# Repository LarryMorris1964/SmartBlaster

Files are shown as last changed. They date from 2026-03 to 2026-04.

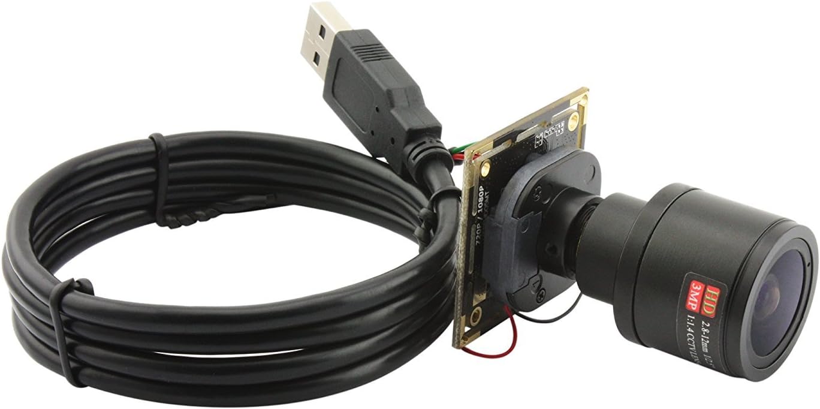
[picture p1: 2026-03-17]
hardware/Reference images/Camera/613zbUWkeIL._AC_SL1500_.jpg

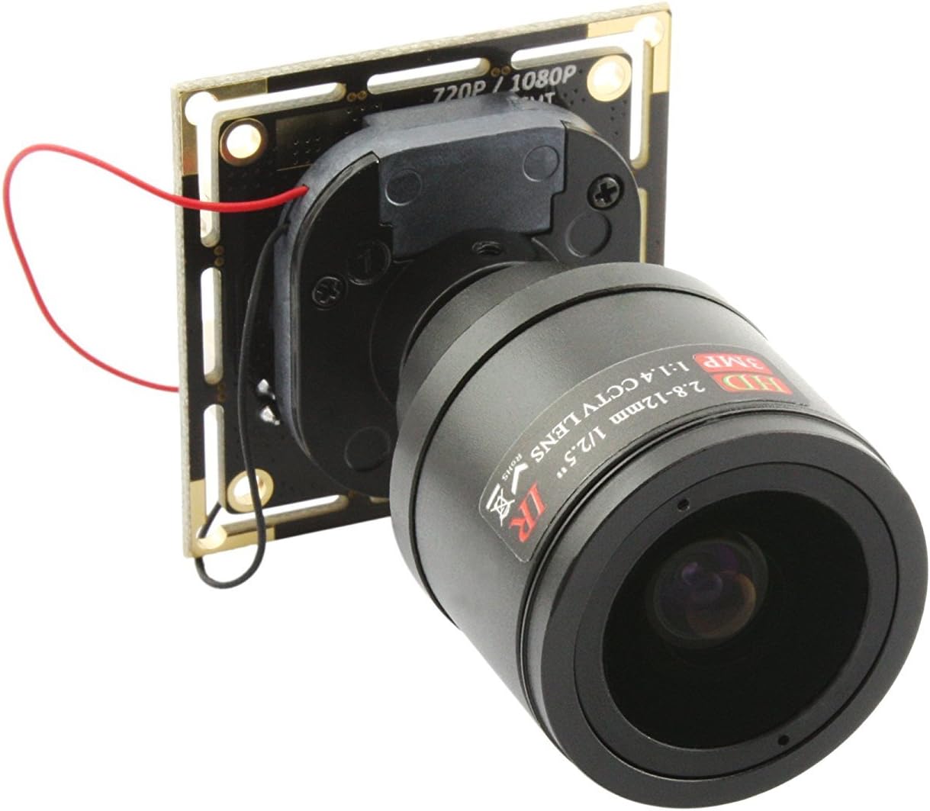
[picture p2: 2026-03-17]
hardware/Reference images/Camera/71GznruDwVL._AC_SL1500_.jpg

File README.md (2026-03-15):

# SmartBlaster — Open Smart HVAC Controller

SmartBlaster is an open-source, wall-mounted HVAC controller featuring:

- A landscape camera for visual feedback
- IR control for mini-splits and AC units
- A sleek, thermostat-like enclosure
- Modular hardware and software design
- Hobbyist-friendly assembly and open collaboration

This repository contains:

- **Hardware** (enclosure CAD, electronics, mechanical specs)
- **Software** (Python-based control logic, drivers, tools)
- **Documentation** (assembly, wiring, printing, troubleshooting)

Contributions are welcome!

A Raspberry Pi-based smart device. This repo contains both hardware design files and the Python software stack.

## Repository Layout

```
SmartBlaster/
├── hardware/
│   ├── enclosure/revA/     3D-printable enclosure parts (.obj)
│   ├── electronics/        Schematics, PCB files, BOM
│   └── mechanical_specs/   Reference dimensions and tolerances
├── software/               Python source, tests, dependencies
├── docs/                   Assembly guide, wiring diagrams, troubleshooting
└── LICENSE
```

## Quick Start

### Hardware
See [docs/assembly_guide.md](docs/assembly_guide.md) for full build instructions and [docs/wiring.md](docs/wiring.md) for wiring diagrams.

3D print files are in `hardware/enclosure/revA/`. All parts are designed for standard FDM printing (PLA or PETG recommended).

### Software
```bash
cd software
python -m venv .venv
source .venv/bin/activate      # Windows: .venv\Scripts\activate
pip install -r requirements.txt
python src/main.py
```

## Hardware Revision History

| Rev | Status | Notes |
|-----|---|---|
| A | Current | Initial release |
| B | Planned | TBD |

## License
See [LICENSE](LICENSE).

## Project Manifest

SmartBlaster is defined by the following core constraints:

- Camera PCB: 32 × 32 mm, 14 mm deep
- Lens: 27 mm diameter, 45 mm long
- Required rear clearance: 14 mm
- IR module: 23.5 × 21.5 mm, 5 mm LED height
- Enclosure internal depth: 61 mm
- Landscape orientation
- IR LED offset: +25 mm X

These constraints drive both the enclosure geometry and the software architecture.

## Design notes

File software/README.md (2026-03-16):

# SmartBlaster Software

Python application that runs on the Raspberry Pi.

## Structure

```
software/
├── src/
│   └── main.py     Entry point
├── tests/          pytest test suite
└── requirements.txt
```

## Setup

```bash
python -m venv .venv
source .venv/bin/activate      # Windows: .venv\Scripts\activate
pip install -r requirements.txt
```

## Run

```bash
python src/main.py
```

## Test

```bash
pytest
```

## Project Diary

An AI-assisted build diary lives in `docs/AI_DIARY.md`.

## Project Backlog

A running project backlog lives in `docs/PROJECT_BACKLOG.md`.

## New Scaffolded Modules

- `src/smartblaster/config.py` — runtime settings from environment variables
- `src/smartblaster/hardware/` — camera + IR adapters
- `src/smartblaster/control/state_machine.py` — HVAC control state skeleton
- `src/smartblaster/services/runtime.py` — runtime wiring and loop

Run with:

```bash
python -m smartblaster
```

## CLI (ESP32 IR Bridge)

Send commands to the ESP32 bridge over serial:

```bash
smartblaster-cli --serial-port COM3 set --mode cool --temp 24 --fan medium --swing vertical
smartblaster-cli --serial-port COM3 off
```

Request thermostat status via camera parse pipeline:

```bash
smartblaster-cli status --model-id midea_kjr_12b_dp_t \
	--history-file data/thermostat_status_history.log
```

Enable diagnostic mode to also save each captured image for verification:

```bash
smartblaster-cli status --diagnostic-save-images --diagnostic-image-dir data/status_images
```

The status request flow is:
- capture camera frame
- parse display indicators (mode/fan/timer/follow-me/power/setpoint)
- append a text-readable JSON-lines history record
- optionally save source image in diagnostic mode

## Offline Vision Validation (No Live Thermostat Required)

You can evaluate parser quality against labeled JPEG samples without a full HVAC system:

```bash
smartblaster-cli vision-eval \
	--model-id midea_kjr_12b_dp_t \
	--images-dir data/samples/midea \
	--labels-file data/samples/midea/labels.jsonl \
	--output-report data/vision_eval_report.json
```

Use `data/samples/midea/labels.sample.jsonl` as a template for labels.

Validate labels before running evaluation:

```bash
smartblaster-cli vision-validate-labels \
	--labels-file data/samples/midea/labels.sample.jsonl \
	--images-dir data/samples/midea
```

If validation fails, the command prints each issue and exits non-zero.

Full label schema reference:
- `data/samples/midea/labels.schema.json`

## Runtime Event Dispatch

The runtime loop now maps high-level events to typed Midea commands:

- `cool_requested` -> COOL command
- `heat_requested` -> HEAT command
- `dry_requested` -> DRY command
- `fan_requested` -> FAN_ONLY command
- `stop_requested` -> OFF command

When state changes, runtime emits a `midea_ir.command` frame via `IrService.send_midea_command()`.

## Daily Automation (Initial Solar Approximation)

Configure fixed daily on/off events via environment variables:

- `SMARTBLASTER_DAILY_ON_TIME` (HH:MM, local time)
- `SMARTBLASTER_DAILY_OFF_TIME` (HH:MM, local time)
- `SMARTBLASTER_TARGET_TEMPERATURE_C`
- `SMARTBLASTER_SOLAR_WEEKLY_SCHEDULE_JSON` (optional per-day override JSON)

Default schedule is 10:00 ON and 15:00 OFF.
Default target setpoint is 26C (about 78.8F).

Example weekly schedule JSON:

```json
{
	"mon": {"on_time": "09:45", "off_time": "15:30"},
	"tue": {"on_time": "10:00", "off_time": "15:00"}
}
```

Current behavior:
- At `DAILY_ON_TIME`, SmartBlaster emits `cool_requested` and sends a COOL command at the target temperature.
- At `DAILY_OFF_TIME`, SmartBlaster emits `stop_requested` and sends OFF.
- Temperature control is sent as an explicit target setpoint in the IR payload (for example 24C), not as temp-up/temp-down button increments.
- Midea IR payload setpoints are encoded in Celsius (`temperature_c`), even when thermostat UI settings may be Fahrenheit-facing.
- Runtime treats thermostat timer state as informational; direct runtime ON/OFF commands are intended to supersede manual timer settings.

Future behavior:
- External stimuli (e.g., inverter/solar surplus signals) can inject events through `EventSource` implementations without replacing runtime/state-machine logic.

## Camera Optional Operation

SmartBlaster supports IR-only operation (no camera attached):

- Set `SMARTBLASTER_CAMERA_ENABLED=false`
- Runtime uses a no-op camera service and still executes all IR scheduling/dispatch

This enables a Sensibo-style launch mode where the device blasts IR commands without visual verification.

## Thermostat Profile Selection

Set `SMARTBLASTER_THERMOSTAT_PROFILE_ID` to select a supported profile from the thermostat library.

Current launch profile:
- `midea_kjr_12b_dp_t`

Profile metadata lives in `src/smartblaster/thermostats/library.py`.

Command execution policy is now profile-driven (criticality, retry count, retry wait), keyed by thermostat profile.
This keeps command behavior extensible across brands/models while reusing the same runtime flow.
At setup time, profile selection determines:
- IR protocol implementation
- camera support availability
- command policy defaults used by runtime (for current logging and future verification/retry orchestration)

## Captive Portal Provisioning Scaffold

Provisioning core logic is implemented in `src/smartblaster/provisioning/service.py`.
It validates setup payloads (Wi-Fi credentials, thermostat profile, camera mode) and persists setup state.

A future local web server/captive portal can call this module directly.

A local setup server scaffold is now available:

```bash
smartblaster-setup-server --host 0.0.0.0 --port 8080
```

Endpoints:
- `GET /` setup page (basic HTML)
- `GET /api/thermostats` profile options from library
- `POST /api/setup` validate and persist onboarding settings
- `GET /api/camera/status` live camera alignment metrics for the selected thermostat profile
- `GET /api/camera/preview.jpg` live preview JPEG with parser overlay banner
- `POST /api/camera/reference-capture` save install-time reference images with JSON metadata

The captive portal setup page now includes a `Camera Setup` section intended for headless installs:
- live preview with overlay
- parser readability/focus/glare feedback
- install-time reference image capture

Reference images are stored under `data/reference_images/<phase>/...` so the same storage layout can be reused later for runtime/support lifecycle snapshots.

Retention behavior:
- phase-specific FIFO retention (oldest captures pruned first, newest retained)
- higher default retention for high-value phases like `runtime_parse_failure`
- lower default retention for bulk phases like `training_periodic`

Offload readiness:
- each capture metadata file tracks offload state (`pending` / `offloaded`), attempt counts, and optional remote IDs
- this is intended to support future periodic upload/offload to a central server without changing on-device capture format

Offload skeleton (future work item):
- runtime includes a disabled-by-default offload worker scaffold that drains pending captures FIFO in batches
- current transport is a no-op placeholder; real server transport/auth/retry policy is still future work

Current lifecycle hook:
- runtime parse failures can automatically save the failed source image, overlay, and error context into the reference-image store

Status request behavior now supports two camera/parse paths:
- strict (`request_status`): used by command-verification logic; camera/parse failures are fatal to that transaction
- best-effort (`request_status_best_effort`): used by opportunistic workflows (for example periodic snapshots); camera/parse failures are non-fatal and returned as typed outcomes

Provisioning now also persists future-facing capture options:
- `reference_capture_on_parse_failure`
- `training_mode_enabled`
- `training_capture_interval_minutes`
- `validate_capabilities_enabled`

The training-mode and capability-validation workflows are not fully automated yet, but their settings now flow through setup state into runtime configuration so later hooks can reuse the same reference-image storage path.

## Device Bootstrap Mode

## Raspberry Pi OS Lite Deployment

Pi OS Lite (64-bit) is sufficient for SmartBlaster.

Deployment assets:
- First-boot setup script: `deploy/install/first_boot_setup.sh`
- Vision package install script (OpenCV, Tesseract, TFLite best-effort): `deploy/install/install_vision_stack.sh`
- Service installer: `deploy/install/install_service.sh`
- systemd unit: `deploy/systemd/smartblaster.service`
- Full image prep checklist: `docs/PI_IMAGE_PREP_CHECKLIST.md`

Typical bring-up flow on Pi:

```bash
cd ~/SmartBlaster/software
sudo ./deploy/install/first_boot_setup.sh
systemctl status smartblaster.service
```

Use one command to choose setup vs runtime automatically:

```bash
smartblaster-device --mode auto --state-file data/device_setup.json
```

Startup behavior:
- If setup state file is missing: run captive setup server mode.
- If setup state file exists: run HVAC runtime mode.

Override manually:
- `--mode setup`
- `--mode run`

Enable AP-mode script orchestration during setup mode:

```bash
smartblaster-device --mode setup --enable-ap-mode \
	--ap-use-sudo \
	--ap-start-script ./deploy/ap/start_ap_mode.sh \
	--ap-stop-script ./deploy/ap/stop_ap_mode.sh
```

For production service users, add a restricted sudoers rule so only AP scripts are permitted:
- [software/deploy/security/smartblaster-apmode.sudoers](deploy/security/smartblaster-apmode.sudoers)

Use real Wi-Fi verification with NetworkManager in setup server mode:

```bash
smartblaster-setup-server --use-nmcli
```

## Service Installation Helpers (Linux/Raspberry Pi)

From `/opt/smartblaster/software`:

```bash
./deploy/install/preflight_check.sh
```

```bash
./deploy/install/post_install_check.sh
```

```bash
sudo ./deploy/install/install_service.sh
```

Optional (skip checks):

```bash
sudo ./deploy/install/install_service.sh --skip-preflight --skip-post-check
```

To uninstall service artifacts:

```bash
sudo ./deploy/install/uninstall_service.sh
```

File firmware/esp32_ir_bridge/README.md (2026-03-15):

# ESP32 IR Bridge Firmware (Reference Scaffold)

This folder contains a reference Arduino sketch for bridging SmartBlaster JSON commands to Midea IR transmissions.

## Goal
- Receive line-delimited JSON over Serial
- Parse `midea_ir.command` envelopes
- Transmit Midea IR packet via `IRremoteESP8266`
- Return `midea_ir.ack` envelope with success/error

## Dependencies
- IRremoteESP8266
- ArduinoJson

## Message Contract
See [docs/architecture/esp32_ir_bridge_contract.md](../../docs/architecture/esp32_ir_bridge_contract.md).

## Wiring (example)
- IR LED transistor driver on `GPIO4` (change in sketch as needed)
- Optional status LED on board LED

## Notes
This is a scaffold and intentionally keeps mode mapping conservative. Extend for model-specific features once captures from KJR-12B-DP-T are validated.

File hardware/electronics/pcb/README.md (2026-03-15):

# PCB — Placeholder
Add PCB layout files here if a custom IR or interface board is designed.
Recommended tools: KiCad, EasyEDA.

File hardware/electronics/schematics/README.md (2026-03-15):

# Schematics — Placeholder
Add schematic files here (e.g., KiCad `.kicad_sch`, PDF exports, or EasyEDA JSON).

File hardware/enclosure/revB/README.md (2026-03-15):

# Rev B — Planned
Placeholder for future enclosure revision. Add OBJ files and a README here when Rev B design begins.

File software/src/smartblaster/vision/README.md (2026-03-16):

# Vision Dataset Evaluation

You can validate parser quality offline using labeled JPEGs (no live HVAC required).

## Why this helps

- Works with sample images at any resolution.
- Lets you build a growing regression suite from real thermostat photos.
- Enables repeatable testing in CI without hardware.

## Label manifest format (JSONL)

Each line:

```json
{"filename":"img_001.jpg","expected":{"mode":"cool","set_temperature":24.0,"temperature_unit":"C","fan_speed":"high","timer_set":true,"follow_me_enabled":false,"power_on":true}}
```

Fields are optional per image. Include only fields you know are correct.

## Run evaluation

```bash
smartblaster-cli vision-eval \
  --model-id midea_kjr_12b_dp_t \
  --images-dir data/samples/midea \
  --labels-file data/samples/midea/labels.jsonl \
  --output-report data/vision_eval_report.json
```

The report includes per-field accuracy and per-image mismatches.

## Render alignment overlays

Use this when tuning landmark normalization and ROI placement:

```bash
smartblaster-cli vision-debug-overlays \
  --model-id midea_kjr_12b_dp_t \
  --images-dir data/samples/midea \
  --output-dir data/debug_overlays
```

For each input image, this writes:

- stem.original_bounds.png: original image with detected display boundary estimate.
- stem.rois_selected.png: parser ROI boxes on the chosen normalized candidate.
- stem.rois_bounds.png: parser ROI boxes on boundary-based normalization (when available).
- stem.rois_identity.png: parser ROI boxes on plain resize fallback (when selected differs).
- stem.digits_global_segments.png: digit ROI + segment activation using global threshold.
- stem.digits_local_segments.png: digit ROI + segment activation using local digit threshold.
- stem.temp_candidates.png: candidate digit ROI boxes and predicted temperatures.

By default, helper files ending in _rois are skipped. Add --include-auxiliary-images to include them.

## Known Workaround

- WORKAROUND: `set_temp` is currently derived from `follow_me` in the parser.
- Why: the `set_temp` glyph is low-contrast/noisy in current sample images and is not yet reliable as a direct detection target.
- TODO: replace this workaround with direct `set_temp` detection once a stable detector is implemented and validated.

## Milestone Status

- Milestone reached on 2026-03-15 for `midea_kjr_12b_dp_t` sample-set tuning.
- Current labeled baseline: all tracked fields evaluate at `1.0` accuracy on the 3-image Midea sample set, with `all_correct_images = 3`.
- Checkpoint commit for the final temperature fix: `8d48815` (`Temperature: add anchored ROI gating and right-shift candidates`).
- Next phase: expand validation with new real hardware captures before changing core parser geometry again.

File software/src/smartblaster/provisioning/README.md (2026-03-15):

# Provisioning Module

This package contains framework-agnostic onboarding logic used by a future captive portal UI.

## Responsibilities
- Validate setup payload (Wi-Fi, thermostat profile, camera mode)
- Verify Wi-Fi credentials (placeholder today; replace with NetworkManager checks)
- Persist device setup state for runtime startup
- Provide thermostat profile list for UI selection

## Integration Target
A local web server (captive portal) should call `ProvisioningService.apply_setup()` and then trigger reboot/network transition.

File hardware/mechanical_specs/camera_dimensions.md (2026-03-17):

# Camera Module Dimensions

## Raspberry Pi Camera Module v2

| Dimension | Value |
|---|---|
| PCB width | 25 mm |
| PCB height | 24 mm |
| PCB thickness | 1 mm |
| Lens protrusion | ~4 mm |
| Ribbon cable connector | 15-pin FFC, top-contact |
| Mounting holes | 2× M2, 21 mm center-to-center |

## Bracket Clearances

- Minimum bracket inner width: **26 mm** (1 mm side clearance each)
- Lens aperture cutout: **9 mm diameter** minimum
- Ribbon cable slot: **17 mm × 3 mm**

## References
- [Official datasheet](https://www.raspberrypi.com/documentation/accessories/camera.html)

# Camera Module Dimensions (large lens module — mechanical drawing)

| Dimension | Value | Source |
|---|---|---|
| Mounting plate | 37 × 37 mm square | drawing |
| Mounting hole C-C spacing | 27 mm (both axes) | drawing (5 mm in from each edge) |
| Mounting screw size | M2.5 (estimated) | drawing |
| Rear barrel OD | 27 mm | drawing |
| Front lens tip OD | 14 mm | drawing |
| Total module depth | ~47 mm | drawing (10+4+5+4+4+11+... ≈ 47) |
| Rear barrel length | 24 mm | drawing |
| Middle section length | 11 mm | drawing |
| Front section depth | ~10 mm | drawing |

## Enclosure Impact
- Front-face aperture needs to clear the 27 mm barrel where it passes through the wall
- Camera boss pattern: 4× bosses at ±13.5 mm from lens centre in both X and Y
| Standoff height (PCB to back wall) | 10 mm | drawing — rear board omitted; back wall of case serves that role |

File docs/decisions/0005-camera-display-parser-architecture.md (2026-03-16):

# ADR 0005: Camera Display Parser Architecture

## Status

Proposed

## Date

2026-03-15

## Context

SmartBlaster camera support should be:

- Model-specific for parsing accuracy.
- Standalone so parsing can evolve independently from control logic.
- Predictable for safety: parser emits structured state + confidence, not direct control actions.

For the first supported thermostat (`midea_kjr_12b_dp_t`), the display includes indicators for:

- Mode (`auto`, `cool`, `dry`, `heat`, `fan_only`)
- Timer ON/OFF
- Follow-me
- Power/ON-OFF
- Fan speed
- Lock
- Setpoint digits
- Unit icon (`C` or `F`)

## Decision

1. **Internal standard unit is Celsius.**
   - Runtime and control logic remain Celsius-centric.
   - Camera parser reads thermostat display unit and value.
   - Conversion is applied at boundaries only.

2. **Use a model-specific parser adapter.**
   - Introduce `ThermostatDisplayParser` protocol.
   - Each supported thermostat model gets a dedicated parser implementation.
   - First implementation target: `MideaKjr12bDpTParser`.

3. **Use a normalized output object.**
   - Parsers return `ThermostatDisplayState` with:
     - canonical fields (`mode`, `set_temperature`, `temperature_unit`, etc.)
     - `confidence_by_field`
     - `unreadable_fields`
     - raw indicator flags for diagnostics

4. **No direct actuation from parser output.**
   - Parser only reports observed state.
   - Control decisions remain in runtime/state-machine layer.

5. **Handle uncertainty explicitly.**
   - Missing/ambiguous fields are represented as `None` or `UNKNOWN`.
   - Downstream logic can gate behavior by confidence thresholds.

## Consequences

### Positive

- Clear separation of concerns.
- Easier model-by-model rollout.
- Safer behavior under uncertain vision reads.

### Trade-offs

- Requires per-model parser maintenance.
- Calibration and test fixtures needed per display model.

## Implementation Notes

Scaffolded modules:

- `software/src/smartblaster/vision/models.py`
- `software/src/smartblaster/vision/parser.py`
- `software/src/smartblaster/vision/midea_kjr_12b_dp_t.py`

These are interface-first and intentionally lightweight, ready for iterative CV implementation.

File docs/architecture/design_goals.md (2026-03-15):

# SmartBlaster design goals

## Core intent

- **Purpose:** Wall-mounted smart IR “blaster” for HVAC (mini-splits, AC units).
- **Form factor:** Looks like a thermostat/appliance, not a camera.
- **Orientation:** Landscape camera, centered, with a clean front face.
- **Audience:** Hobbyists and tinkerers, but with a professional, finished feel.

## Hardware goals

- **Minimal hardware footprint:** Small, wall-mounted enclosure with no dangling dongles.
- **Hobbyist-friendly:** Off-the-shelf camera and IR modules, 3D-printable enclosure.
- **Modular:** Enclosure, electronics, and software can evolve independently.
- **Upgradable IR path:** Start with a simple IR module, allow future higher-power emitters.

## Software goals

- **Modular architecture:** Separate drivers, control logic, and UI.
- **Closed-loop capable:** Room to add sensing/feedback later (temp, camera-based checks).
- **Local-first:** Works standalone; cloud/Home Assistant integration is optional.
- **Testable:** Drivers and logic covered by unit tests where practical.

## Collaboration goals

- **Open-source:** Clear structure, documented decisions, easy to fork and extend.
- **Reproducible:** Dimensions, BOM, and build steps are all captured in the repo.
- **Revision-safe:** Hardware revisions are explicit (`revA`, `revB`, …), not overwritten.

## Product Goals
- Reliable autonomous operation on Raspberry Pi hardware
- Practical DIY assembly using 3D-printed enclosure parts
- Clear documentation for wiring, assembly, and troubleshooting
- Wall‑mounted, appliance‑like device
- Landscape camera orientation
- IR control for HVAC
- Open‑source, hobbyist‑friendly
- Modular hardware + software
- Enclosure independent from software development

## Engineering Goals
- Keep hardware/software boundaries explicit
- Prefer serviceable mechanical design (easy opening/rework)
- Keep wiring simple and reproducible
- Make software testable outside full hardware context where possible

## Non-goals (for now)
- Cloud dependency for core local control
- Complex custom PCB before validating revA behavior
- Over-optimization before first stable end-to-end prototype

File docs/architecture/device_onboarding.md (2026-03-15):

# Device Onboarding (Captive Portal First)

## Goal
Allow non-technical users to power on SmartBlaster and complete setup from a phone without Raspberry Pi knowledge.

## First-Boot Flow
1. Device enters provisioning mode and exposes temporary Wi-Fi AP (e.g., `SmartBlaster-XXXX`).
2. User connects with phone; captive portal opens setup page.
3. User enters:
   - Home Wi-Fi SSID/password
   - Thermostat make/model profile
   - Camera enabled/disabled
4. Device validates inputs, saves config, exits provisioning mode, and joins home Wi-Fi.

## Current Implementation Scaffold
- Provisioning core logic: [software/src/smartblaster/provisioning/service.py](../../software/src/smartblaster/provisioning/service.py)
- Thermostat profile library: [software/src/smartblaster/thermostats/library.py](../../software/src/smartblaster/thermostats/library.py)
- Captive portal web scaffold: [software/src/smartblaster/provisioning/web.py](../../software/src/smartblaster/provisioning/web.py)

Run locally:
- `smartblaster-setup-server --host 0.0.0.0 --port 8080`

Device bootstrap entrypoint:
- `smartblaster-device --mode auto --state-file data/device_setup.json`
- `auto` mode selects setup portal when state is missing, otherwise runtime mode.

## Launch Constraints
- IR-only mode is fully supported (`camera_enabled=false`).
- Camera verification routines are model-specific and initially enabled only for Midea KJR-12B-DP-T profile.
- Minimum launch requirement is selecting a known IR profile from library and storing Wi-Fi credentials.

## Future Extensions
- Replace fixed schedule with inverter/solar event source integration.
- Add camera OCR/vision pipelines per thermostat profile incrementally.
- Add BLE-assisted provisioning as optional fallback, while keeping captive portal as default path.

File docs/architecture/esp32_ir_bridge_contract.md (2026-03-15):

# ESP32 IR Bridge Contract (Pi ↔ ESP32)

This document defines the serial/MQTT JSON contract between SmartBlaster (Pi) and an ESP32 IR transmitter service.

## Protocol Version
- `v = 1`

## Command Envelope (Pi → ESP32)

Topic: `midea_ir.command`

```json
{
  "v": 1,
  "topic": "midea_ir.command",
  "request_id": "b812eb2f-93dc-404f-8ded-94d04a44bd6d",
  "payload": {
    "mode": "cool",
    "temperature_c": 24,
    "fan": "medium",
    "swing": "vertical",
    "preset": "none",
    "beeper": false
  }
}
```

### Payload Fields
- `mode`: `off|auto|cool|heat|dry|fan_only`
- `temperature_c`: required for non-`off`, range `17..30`
- `fan`: `auto|low|medium|high|silent|turbo`
- `swing`: `off|vertical|both`
- `preset`: `none|sleep|eco|boost`
- `follow_me_c`: optional, range `0..37`
- `beeper`: boolean

## ACK Envelope (ESP32 → Pi)

Topic: `midea_ir.ack`

Success:
```json
{"v":1,"topic":"midea_ir.ack","request_id":"...","ok":true}
```

Failure:
```json
{"v":1,"topic":"midea_ir.ack","request_id":"...","ok":false,"error_code":"invalid_command","error_message":"temperature_c out of range"}
```

## Standard Error Codes
- `bad_json`
- `bad_schema`
- `unsupported_version`
- `invalid_command`
- `tx_failed`

## Python Reference Implementation
- Encoder/parser helpers: [software/src/smartblaster/ir/esp32_schema.py](../../software/src/smartblaster/ir/esp32_schema.py)
- Typed command model: [software/src/smartblaster/ir/command.py](../../software/src/smartblaster/ir/command.py)

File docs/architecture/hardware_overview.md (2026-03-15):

# Hardware Overview

## Camera module

- **PCB size:** 32 × 32 mm.
- **PCB depth:** 14 mm.
- **Lens diameter:** 27 mm.
- **Lens length:** 45 mm (front glass → PCB front).
- **Required rear clearance:** 14 mm behind PCB to inner back shell.

## IR module

- **Board size:** 23.5 × 21.5 mm.
- **LED height:** 5 mm above board.
- **IR window:** 6 mm circular opening in front shell.
- **Range:** Nominally ~1.3 m for the current module; design allows upgrading to stronger emitters.

## Enclosure constraints

- **Internal depth (front inner → back inner):** 61 mm.
  - 45 mm lens stack.
  - 14 mm rear clearance.
  - ~2 mm lens setback behind inner front surface.
- **Lens:** Centered on front face, landscape orientation.
- **IR LED:** Offset (e.g., +25 mm in X) with its own window.
- **Mounting:** Backplate with a 1/4-20 style boss (Blink-like) for wall mounting or brackets.
- **Ventilation:** Side/perimeter venting to avoid “boxy” look and allow airflow.

## Upgrade paths

- **IR:** Replace the simple IR module with a higher-power LED + transistor driver, keeping the same LED position.
- **Sensors:** Add temperature/humidity sensors inside or near the enclosure.
- **Compute:** Swap Pi variants as long as mounting and power constraints are respected.

## Core Hardware
- Camera dimensions
- IR module dimensions
- Required clearances
- Enclosure depth calculation
- Mounting strategy
- Ventilation strategy

- Raspberry Pi (primary compute)
- Camera module mounted via `camera_bracket`
- IR emitter/receiver path mounted via `ir_mount`
- Power input via USB-C

## Mechanical Stack
- Enclosure files: `hardware/enclosure/revA/`
- Mechanical constraints: `hardware/mechanical_specs/camera_dimensions.md`

## Electrical Artifacts
- BOM: `hardware/electronics/bill_of_materials.csv`
- Schematics placeholder: `hardware/electronics/schematics/`
- PCB placeholder: `hardware/electronics/pcb/`

## Open Hardware Work Items
- Finalize selected camera SKU and tolerances
- Validate IR range and line-of-sight geometry
- Add schematic PDFs and source files

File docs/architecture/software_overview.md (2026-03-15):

# Software Overview
# Software overview

## Structure

- `software/src/smartblaster/`
  - `camera.py` — camera access and basic capture/inspection.
  - `ir_driver.py` — IR encoding and transmission.
  - `control_logic.py` — HVAC control decisions and state machine.
  - `ui.py` — local UI or integration hooks (e.g., web UI, Home Assistant).
  - `__init__.py` — package initialization.
- `software/src/main.py` — entry point / launcher.
- `software/tests/` — unit tests (e.g., IR encoding, control logic).
- `software/tools/` — utilities (e.g., IR code capture, diagnostics).

## Responsibilities

- **Camera layer:**
  - Initialize camera.
  - Provide frames or snapshots for diagnostics or future feedback loops.

- **IR driver:**
  - Represent IR codes (protocol, carrier frequency, timings).
  - Transmit codes via GPIO/USB-attached IR hardware.
  - Provide a way to add HVAC-specific code sets.

- **Control logic:**
  - Decide when to send IR commands (on/off, mode, temperature).
  - Maintain internal state (target vs. actual).
  - Allow manual overrides and schedules.

- **UI / integration:**
  - Local configuration (files, simple UI, or API).
  - Optional integration with Home Assistant / other ecosystems.

## Non-goals (for now)

- Full-blown cloud backend.
- Complex computer vision.
- Multi-room orchestration.

These can be layered on later if the core remains clean and modular.

## Runtime
- Python project structure
- Drivers (camera, IR)
- Control logic
- UI layer
- Configuration system
- Logging

- Language: Python 3.9+
- Entry point: `software/src/main.py`
- Dependencies: `software/requirements.txt`

## Responsibilities
- Initialize hardware interfaces (GPIO/camera/IR)
- Run control loop / event handlers
- Emit control outputs and collect diagnostics

## Testing
- Test location: `software/tests/`
- Test runner: `pytest`

## Near-term Software Milestones
1. Define module boundaries (camera, ir, control, telemetry)
2. Add configuration model for GPIO and timings
3. Add automated tests for control logic
4. Add deployment process for Raspberry Pi target

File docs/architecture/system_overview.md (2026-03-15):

# SmartBlaster system overview
SmartBlaster is a Raspberry Pi-based device combining custom enclosure hardware, camera sensing, IR interaction, and software control.

## High-level components

- **Compute:** Raspberry Pi (e.g., Zero 2 W or similar).
- **Camera:** USB camera module with 32 × 32 mm PCB and 27 mm lens.
- **IR transmitter:** Small IR module with a 5 mm LED for blasting HVAC IR codes.
- **Enclosure:** 3D-printed, wall-mounted, landscape-oriented front face.
- **Power:** USB power to the Pi (and through it to camera/IR as needed).

## Data/control flow

1. **Inputs:**
   - Optional: temperature sensors, user configuration, schedules.
   - Optional: camera-based feedback (e.g., indicator LEDs, status).

2. **Processing:**
   - Control logic decides when and how to send IR commands.
   - IR driver encodes and transmits HVAC-specific IR sequences.

3. **Outputs:**
   - IR signals to HVAC unit.
   - Optional UI feedback (LEDs, on-screen, or remote dashboard).
   Status and diagnostics are logged for troubleshooting

## Separation of concerns

- **Hardware:** Defines physical constraints and mounting.
- **Electronics:** Defines wiring, power, and signal paths.
- **Software:** Implements behavior, protocols, and integrations.
- **Docs:** Capture decisions, constraints, and assembly steps.

## Repository Mapping
- Hardware: `hardware/`
- Software: `software/`
- Build + troubleshooting docs: `docs/`

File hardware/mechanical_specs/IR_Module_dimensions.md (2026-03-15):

# IR Module Dimensions

- Board: 23.5 × 21.5 mm
- LED height: 5 mm
- Window: 6 mm circular opening

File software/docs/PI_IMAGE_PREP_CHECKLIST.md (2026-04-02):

# Raspberry Pi Image Preparation Checklist

Target: Raspberry Pi OS Lite (64-bit)

## 1. Flash OS Image

1. Open Raspberry Pi Imager.
2. Choose OS: Raspberry Pi OS Lite (64-bit).
3. Choose your SD card.
4. In Advanced Options:
- Set hostname (example: `smartblaster-pi`)
- Enable SSH
- Set username/password
- Configure Wi-Fi country (required for AP/network tooling)
- Optionally preconfigure home Wi-Fi for first boot SSH access only (does not bypass SmartBlaster setup/calibration)
5. Write image and safely eject SD card.

## 2. First Boot OS Hardening and Updates

1. Boot Pi and SSH in.
tail -f upgrade.log

2. Update packages:

```bash
sudo apt-get update
sudo apt-get -y upgrade | tee upgrade.log
# Note that the upgrade step reboots processes and will break your remote connect.  So we tee it to a log file and monitor the output after reconnecting
tail -f upgrade.log
# once the upgrade finally finishes we can move on
sudo apt install git -y
sudo reboot
```

3. After reboot, set timezone and locale if needed:

```bash
sudo raspi-config
```

## 3. Copy SmartBlaster Software

1. Copy repo to Pi (or clone):

```bash
git clone https://github.com/LarryMorris1964/SmartBlaster.git ~/SmartBlaster
cd ~/SmartBlaster/software
```

2. Run first-boot setup script:

```bash
sudo ./deploy/install/first_boot_setup.sh
```

This installs Python/runtime packages, vision stack, and systemd service.

## 4. Validate Install

1. Service should be active:

```bash
systemctl status smartblaster.service
```

2. Health endpoint should respond:

```bash
curl -fsS http://127.0.0.1:8080/health
```

3. Review logs:

```bash
journalctl -u smartblaster.service -n 100 --no-pager
```

4. AP/Wi-Fi sanity checks (recommended on first boot):

```bash
# Confirm Wi-Fi driver reports AP support
iw list | grep -A 10 "Supported interface modes"

# Confirm AP dependencies are present/running when setup mode is active
sudo systemctl status hostapd dnsmasq --no-pager

# If setup SSID is not visible on phone, inspect service logs again
sudo journalctl -u smartblaster.service -n 120 --no-pager
```

You should see `AP` listed in supported interface modes. If not, AP mode will not work reliably.

## 5. Files That Must Exist On Device

- Software root: `/opt/smartblaster/software`
- First-boot script: `/opt/smartblaster/software/deploy/install/first_boot_setup.sh`
- Vision package script: `/opt/smartblaster/software/deploy/install/install_vision_stack.sh`
- Service installer: `/opt/smartblaster/software/deploy/install/install_service.sh`
- Systemd unit file: `/opt/smartblaster/software/deploy/systemd/smartblaster.service`

## 6. Notes

- Pi OS Lite is sufficient for SmartBlaster.
- https://www.xda-developers.com/how-to-ssh-into-raspberry-pi/ set up SSH access
- Handy tools for copying files, etc
	- Putty is an all-in-one tool for Pi https://www.circuitbasics.com/use-putty-to-access-the-raspberry-pi-terminal-from-a-computer/ 
	- FileZilla makes transfer easy https://filezilla-project.org/
	- WinSCP is another nice alternative
- then configure Pi Connect https://connect.raspberrypi.com/devices 

- SmartBlaster uses FastAPI + camera/IR services and does not require desktop UI.
- `tflite-runtime` installation is best-effort because wheel availability depends on Python version and architecture.
- First boot still enters setup mode until setup state is saved; Wi-Fi connectivity alone does not skip setup.

**WiFi Setup Info:**
The default WiFi SSID for setup is `SmartBlaster-SETUP` and the default password is `smartblast-setup` (see `deploy/ap/hostapd.conf`).
When connecting to the SmartBlaster-SETUP WiFi network, use this password unless you have customized it in the configuration file.

**Accessing the Captive Portal:**
After connecting to the SmartBlaster-SETUP WiFi, open a browser and go to:

	http://192.168.4.1:8080

This will bring up the SmartBlaster setup portal to complete device configuration.

## 7. Routine Update Workflow (After Initial Install)

Use this for normal code changes so you do not need a long manual sequence each time:

```bash
cd ~/SmartBlaster/software
./deploy.sh
```

What this does:

- Pulls latest code with fast-forward only.
- Ensures the service venv exists.
- Reinstalls SmartBlaster package and dependencies into that venv.
- Reinstalls systemd unit from repo, reloads daemon, and restarts service.

Use deeper recovery steps only if this one-command flow fails.

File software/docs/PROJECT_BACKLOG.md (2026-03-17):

# SmartBlaster Project Backlog

This file is the running backlog for the project. Keep items here even when they span multiple days.

## Active Backlog

### 1. Weekly Scheduling in Main Runtime

Status: Planned

Goals:
- Execute simple on/off automation at configured times inside the main runtime loop.
- Support a per-day weekly schedule as the runtime source of truth.
- Preserve a backward-compatible path from legacy daily on/off settings.
- Keep any setup or admin surface limited to configuration, not schedule execution.

Notes:
- The captive portal may collect or edit schedule values, but scheduling itself belongs to the main program.
- Keep first version simple and deterministic.

### 2. Setup Validation Workflow (IR Capability Shakeout)

Status: Done — initial version shipped

Goals:
- Add a setup validation action that executes each IR command expected for the selected profile. ✓
- Capture camera-parsed state after each command step and compare against expected mode. ✓
- Record pass/fail, parse confidence, and any error reason per step. ✓
- Produce a `ValidationReport` JSON artifact returned from the portal endpoint. ✓

Implementation:
- `src/smartblaster/services/setup_validation.py` — `SetupValidator`, `ValidationReport`, `ValidationStepResult`
- Sequences: cool → heat → dry → fan_only → off (leaves unit powered down)
- Portal endpoint: `POST /api/validation/run` (`ValidationRunPayload`, returns report JSON)
- Portal UI: Validation panel (visible only when camera is enabled), `settle_seconds` input, results table
- 15 tests in `tests/test_setup_validation.py`; sleep-fn injected for zero-latency testing

Open follow-ups:
- Wire `activity_log.ir_command_verified` / `ir_command_verification_failed` into validation steps (covered by backlog item 4).
- Persist report to disk and add history endpoint for later review.

### 3. Portal Form Pre-Population from Saved State

Status: Planned

Goals:
- On portal load, fetch existing saved state from a new `GET /api/setup` endpoint.
- Populate all form fields (device name, Wi-Fi, profile, schedule, camera settings, inverter, etc.) with saved values.
- If no saved state exists, form stays at defaults — no change to current behavior.

Notes:
- Currently the form always opens blank; users redoing setup must re-enter everything.
- Endpoint should return the raw saved state dict; JS maps keys to input element IDs.

### 4. Home Automation Integration Design

Status: Planned

Goals:
- Define first integration architecture for IFTTT.
- Define first integration architecture for Amazon Alexa.
- Define first integration architecture for Apple/HomeKit and related ecosystems.
- Specify the minimum SmartBlaster API/event surface needed to support these integrations.

Notes:
- Start with architecture and interface contracts before implementation.

### 4. Rich Logging and Diagnostics

Status: In progress — core infrastructure complete; integration points to grow

Goals:
- Emit structured JSON activity records for all key interactions: IR commands sent, camera verification results, scheduling events, async events (solar/inverter), and home automation API commands.
- Write records to a rotating JSONL file (`data/activity_log.jsonl` by default, configurable via `SMARTBLASTER_ACTIVITY_LOG_FILE`).
- Use `structlog` over stdlib `logging`; capture logs in tests via `structlog.testing.capture_logs()`.
- Wire `home_automation_command` calls into future IFTTT/Alexa/HomeKit integration layer as it is built.
- Add `ir_command_verified` / `ir_command_verification_failed` call sites once the setup validation workflow (item 2) is implemented.

Notes:
- `ActivityLogger` is fully injectable — pass a custom instance in tests, or let runtime create one from config.
- `configure_logging()` is called once by `SmartBlasterRuntime.from_env()` at startup.

### 5. Extend Logging to Setup / Portal Phase

Status: Planned

Goals:
- Call `configure_logging()` at the start of bootstrap regardless of mode (setup or run).
- Emit activity records for setup-phase events: setup saved, Wi-Fi configured, network failover into portal, portal reboot triggered, auto-recovery loop outcome.
- Wire `ActivityLogger.setup_saved()` into `ProvisioningService.apply_setup()`.
- Persist log to the same rotating JSONL file used by the runtime phase.

Notes:
- Currently `configure_logging()` is only called from `SmartBlasterRuntime.from_env()`, so setup-mode events only go to stderr.
- Bootstrap already has an `ActivityLogger.network_failover` call at the runtime→setup failover point.

## Completed

- None yet.

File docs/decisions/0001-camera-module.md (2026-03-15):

# ADR 0001: Camera Module Selection

## Status

Accepted

## Context

SmartBlaster needs a front-facing camera for:

- Visual feedback (e.g., alignment, diagnostics).
- Future potential closed-loop features.

The camera must fit inside a compact, wall-mounted enclosure and support a landscape orientation.

## Decision

Use a USB camera module with:

- **PCB:** 32 × 32 mm.
- **PCB depth:** 14 mm.
- **Lens diameter:** 27 mm.
- **Lens length:** 45 mm (front glass → PCB front).
- **Rear clearance:** 14 mm behind PCB to inner back shell.

The lens is:

- Centered on the front face.
- Oriented in landscape.
- Flush-mounted behind a chamfered window for a non-camera appliance look.

## Consequences

- Enclosure depth and internal layout are constrained by the 45 mm lens stack + 14 mm rear clearance.
- Future camera swaps must respect these dimensions or trigger a new hardware revision.
- Software can assume a fixed camera position and orientation.
- Status: Proposed
- Date: 2026-03-15

## Context
- Why we chose this camera
- Dimensions
- Landscape orientation
- Flush‑mount lens design

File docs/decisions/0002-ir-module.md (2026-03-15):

# 0002 — IR module and range

## Status

Accepted (with upgrade path)

## Context

SmartBlaster must send IR commands to HVAC units at ~3 m / 10 ft.  
The initial IR module under consideration has a nominal range of ~1.3 m.

## Decision

- Use a small IR module with:
  - **Board:** 23.5 × 21.5 mm.
  - **LED:** 5 mm package, 5 mm height.
- Place the LED behind a 6 mm circular window, offset from the camera (e.g., +25 mm in X).
- Design the enclosure and mounting so:
  - A standard 5 mm IR LED position is fixed.
  - The PCB footprint allows for a future custom or higher-power IR driver.

## Consequences

- Rev A may have limited range depending on drive current and LED characteristics.
- The enclosure does **not** need to change if the IR electronics are upgraded, as long as the LED remains in the same physical position.
- Software can treat the IR path as a pluggable driver (simple module now, more advanced later).
- Status: Proposed
- Date: 2026-03-15

## Context
- Range concerns
- Upgrade path
- LED height
- Window placement

SmartBlaster needs IR transmit only for initial Midea thermostat goals. Receive capability for control and verification could be valuable in future use cases.

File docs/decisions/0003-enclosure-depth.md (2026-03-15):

# ADR 0003: Enclosure Depth Constraint
# 0003 — Enclosure depth and internal stack

## Status

Accepted

## Context

The enclosure must:

- House the camera module and lens.
- Provide clearance behind the PCB for mounting and cabling.
- Maintain a slim, wall-mounted profile.

We have:

- 45 mm from lens front to PCB front.
- 14 mm required clearance behind PCB.

## Decision

Set the **internal depth** (front inner surface → back inner surface) to:

- **61 mm total**, composed of:
  - 45 mm lens stack.
  - 14 mm rear clearance.
  - ~2 mm lens setback behind the inner front surface.

The external depth will be slightly larger (front/back wall thickness).

## Consequences

- All internal components (Pi, IR module, wiring) must fit within this 61 mm envelope.
- The front face can remain visually slim while still accommodating the optics.
- Any future camera with a significantly different stack length will require a new enclosure revision.

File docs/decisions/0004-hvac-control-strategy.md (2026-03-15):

# ADR 0004: HVAC Control Strategy
# 0004 — HVAC control strategy

## Status

Planned

## Context

SmartBlaster’s primary function is to control HVAC units (e.g., mini-splits) via IR.  
Different units use different IR protocols and state models.

## Decision

- Use an **IR blasting** approach:
  - Encode and send full IR commands (mode, temp, fan, etc.).
  - Maintain an internal representation of the desired HVAC state.
- Start with:
  - Manual configuration of IR codes per device.
  - A simple state machine for on/off, mode, and temperature.
- Design the software so:
  - IR protocols are pluggable.
  - Closed-loop feedback (e.g., temperature sensors, camera-based checks) can be added later.
Use a conservative state-machine approach with explicit command pacing, confirmation checks, and safe fallbacks.

### Triggering roadmap

1. **Phase 1 (now): timed automation**
  - Use fixed daily ON/OFF times.
  - ON event sends COOL command at configured setpoint.
  - OFF event sends power-off command.

2. **Phase 2 (future): external energy stimuli**
  - Replace or augment timed triggers with inverter/charger surplus signals.
  - Keep the same state machine and IR dispatch path.
  - Implement external integrations as event sources so the control core remains unchanged.

## Rationale
- Prevents rapid command bursts and inconsistent device state
- Easier to test and reason about than ad-hoc command logic
- Supports later expansion with scheduling and sensor feedback

## Consequences

- Initial versions may rely on user-provided IR codes or captured sequences.
- The control logic must be robust to “stateless” IR (no direct feedback from the HVAC unit).
- Future enhancements (sensors, cloud integration) can build on the same core model.
- Requires explicit state definitions and transition tests
- Adds upfront design overhead but improves reliability
- Timing-based operation may be imperfect vs true energy-aware control, but provides a low-risk path to validate automation and IR reliability before inverter integration.

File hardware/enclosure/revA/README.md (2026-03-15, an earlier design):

# SmartBlaster Enclosure — Rev A

This is the first working enclosure for the SmartBlaster HVAC controller.

## Included Parts

| File | Description |
|---|---|
| `smartblaster_front.obj` | Front face panel |
| `smartblaster_back.obj` | Rear panel with port cutouts |
| `camera_bracket.obj` | Camera module mounting bracket |
| `ir_mount.obj` | IR sensor/emitter mount |
| `pi_standoffs.obj` | Raspberry Pi PCB standoff posts |
| `blink_mount.obj` | Raspberry Pi PCB standoff posts |

## Print Settings (recommended)

- **Material**: PLA or PETG
- **Layer height**: 0.2 mm
- **Infill**: 20%
- **Supports**: Required for `camera_bracket.obj` and `ir_mount.obj`

## Assembly
See [docs/assembly_guide.md](../../../../docs/assembly_guide.md) for step-by-step instructions.

## Notes

- Designed for landscape camera orientation
- Flush-mounted lens behind a chamfered window
- IR LED positioned at +25 mm X offset
- Pi standoffs sized for Raspberry Pi Zero 2 W (adjustable)
- Backplate includes Blink-style 1/4-20 mount boss

See `/docs/enclosure_printing.md` for print settings.

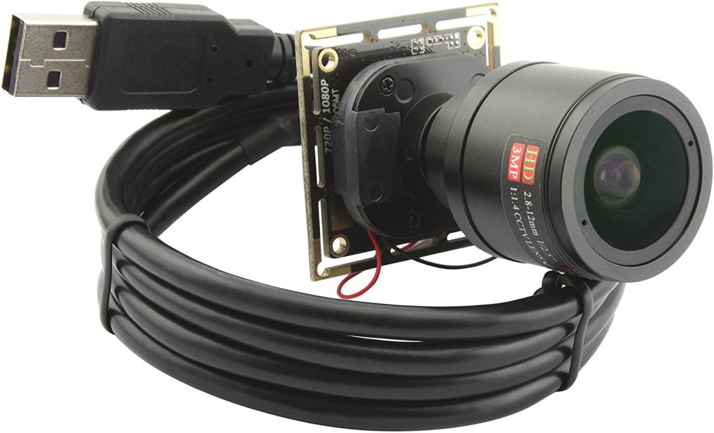
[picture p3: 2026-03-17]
hardware/Reference images/Camera/7159VWa116L._AC_SL1500_.jpg

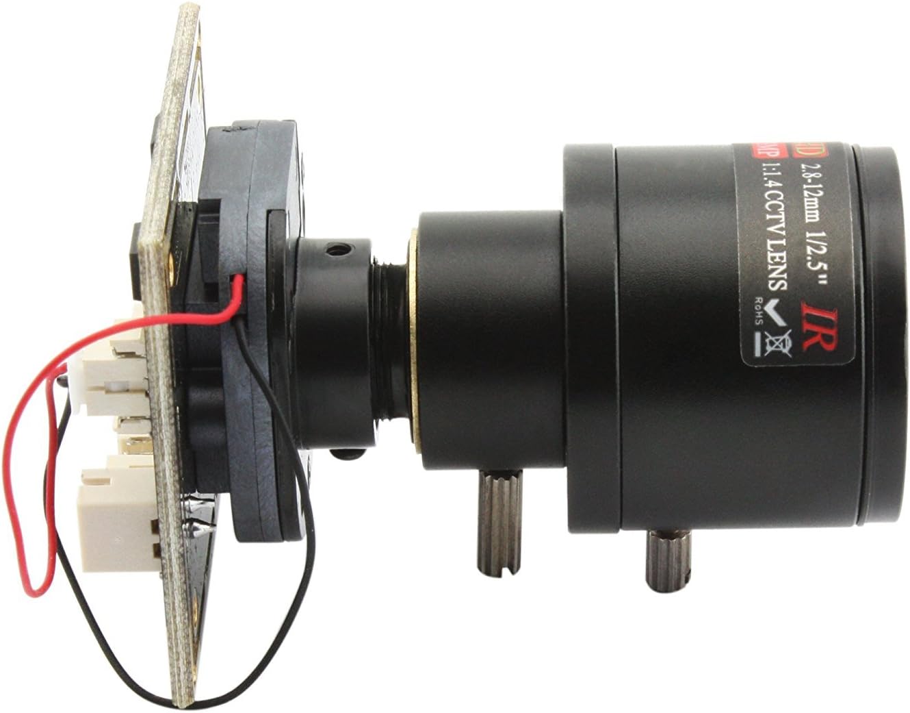
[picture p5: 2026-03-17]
hardware/Reference images/Camera/713zoVsIj+L._AC_SL1500_.jpg

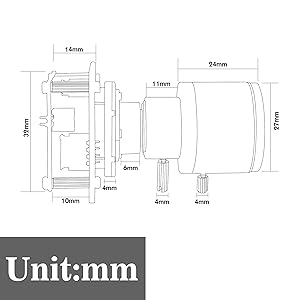
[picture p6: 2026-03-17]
hardware/Reference images/Camera/6ca00281-05a6-41dd-8136-be1aac52e2d8.__CR0,0,2000,2000_PT0_SX300_V1___.jpg

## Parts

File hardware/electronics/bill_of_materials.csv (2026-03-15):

Reference | Quantity | Description | Manufacturer | Part Number | Supplier | Supplier PN | Unit Price | Notes
RPi | 1 | Raspberry Pi 4 Model B 4GB | Raspberry Pi Foundation | SC0194 | Adafruit | 3775
Camera | 1 | Raspberry Pi Camera Module v2 | Raspberry Pi Foundation | SC0023 | Adafruit | 3099
IR_TX | 2 | IR LED 940nm 5mm | Vishay | TSAL6400 | DigiKey | 751-1203-ND
IR_RX | 1 | IR Receiver 38kHz | Vishay | TSOP38238 | DigiKey | 751-1227-ND
PSU | 1 | 5V 3A USB-C Power Supply |  |  |  |  | Replace with specific supplier

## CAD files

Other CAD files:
hardware/enclosure/revA/smartblaster_back.obj
hardware/enclosure/revA/smartblaster_front.obj
hardware/enclosure/revA/pi_standoffs.obj
hardware/enclosure/revA/ir_mount.obj
hardware/enclosure/revA/camera_bracket.obj
hardware/enclosure/revA/SCAD/smartblaster_reva.scad

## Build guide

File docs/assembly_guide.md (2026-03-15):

# Assembly Guide

Step-by-step instructions for building the SmartBlaster enclosure and mounting all components.

## Parts Required
- All 3D-printed parts from `hardware/enclosure/revA/`
- Components listed in `hardware/electronics/bill_of_materials.csv`
- M2×6 screws ×4 (Pi standoffs)
- M2×4 screws ×2 (camera bracket)

## Steps

### 1. Print all enclosure parts
Print each `.obj` file from `hardware/enclosure/revA/`. See the [enclosure README](../hardware/enclosure/revA/README.md) for recommended print settings.

### 2. Mount Raspberry Pi
- Press Pi into `pi_standoffs` posts
- Secure with M2×6 screws

### 3. Install camera
- Attach ribbon cable to Pi CSI port before mounting
- Snap camera PCB into `camera_bracket`
- Secure bracket with M2×4 screws

### 4. Install IR components
- Seat IR LED and receiver into `ir_mount`
- Route wires per [wiring.md](wiring.md)

### 5. Close enclosure
- Align `smartblaster_front` with `smartblaster_back`
- Snap or screw closed (hardware TBD)

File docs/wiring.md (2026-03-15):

# Wiring Guide

All connections between the Raspberry Pi GPIO header and external components.

## Pin Reference (BCM numbering)

| GPIO | Function | Component | Notes |
|---|---|---|---|
| 4 | IR TX | IR LED (via 100Ω resistor) | |
| 17 | IR RX | TSOP38238 OUT pin | |
| — | 5V | IR receiver VCC | |
| — | GND | IR LED cathode, receiver GND | |

## Camera
- Connected via CSI ribbon cable (15-pin FFC) — no GPIO required

## Power
- Pi powered via USB-C (5V 3A minimum)
- IR components powered from Pi 5V header pin

## Diagram
_Add a wiring diagram image here (e.g., Fritzing export)._

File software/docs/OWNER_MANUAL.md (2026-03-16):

# SmartBlaster Owner's Manual

## 1. What SmartBlaster Does
SmartBlaster controls an HVAC remote over IR and can optionally read thermostat status using a camera.

Core functions:
- Scheduled daily cooling window with configurable start/stop times
- Target temperature control with thermostat profile support
- Optional camera verification for display readability and parser confidence
- Optional inverter-triggered cooling behavior

## 2. First-Time Setup
Use the captive portal page on first boot.

1. Connect to the SmartBlaster access point.
2. Open the setup portal page.
3. Enter a device name.
4. Enter your home Wi-Fi SSID and password.
5. Select your thermostat profile from a list of supported thermostats.
6. Enable camera command-verification if your device includes a camera.
7. Save setup.

If camera verification is enabled:
1. Open Camera Setup in the portal.
2. Align camera framing so the thermostat display is clearly visible, and zoomed so that the thermostat fills the image.
3. Check focus, glare.  Setup will show parser confidence values, indicating whether the images are succesfully processed.
4. Save a reference image labeled installer-approved.

## 3. Setup Page Fields
Important fields:
- Device Name: Friendly name shown in setup and runtime metadata.
- Daily Cool Start/Stop: 24-hour HH:MM local time.
- Target Temperature: Desired setpoint for cool mode.
- Thermostat Temperature Unit: Must be supported by selected profile.
- Active Days: Comma-separated day list (mon..sun).

Advanced fields:
- Inverter controls: Start/stop thresholds and source type.
- Status diagnostics: Save status history and optional status images.
- Reference capture options: Parse-failure capture, training mode, offload settings.

## 4. Normal Operation
After setup is saved, SmartBlaster can run in runtime mode.

Typical behavior:
- Applies profile-supported commands for cooling, fan, and swing.
- Uses policy metadata to classify command verification behavior.
- Captures status snapshots and reference images when configured.
- Uses explicit mode + set-temperature IR commands (absolute setpoint), not incremental temp up/down steps.
- Treats thermostat timer state as non-authoritative; runtime ON/OFF commands override timer outcomes.

## 5. Troubleshooting
- Wi-Fi setup fails:
  - Re-check SSID/password and signal quality.
- Camera status not readable:
  - Reposition camera, increase lighting, reduce glare.
- Low parser confidence:
  - Save a clean reference image and verify profile selection.
- Unit does not respond to commands:
  - Confirm IR emitter placement and thermostat profile.

## 6. Safety Notes
- Do not block thermostat vents or safety sensors.
- Keep SmartBlaster and power supplies dry.
- Treat camera captures as potentially sensitive operational data.

## 7. Maintenance
- Keep lens clean and thermostat display unobstructed.
- Review status/reference storage periodically.
- Update software when newer builds are available.

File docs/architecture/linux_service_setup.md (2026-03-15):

# Linux Service + AP Mode Setup

This is the first production-style deployment scaffold for Raspberry Pi.

## Systemd service
- Unit file: [software/deploy/systemd/smartblaster.service](../../software/deploy/systemd/smartblaster.service)
- Runs bootstrap command in `auto` mode.
- Uses setup state file: `/var/lib/smartblaster/device_setup.json`.

Recommended setup-mode command options (service or manual):
- `--enable-ap-mode`
- `--ap-use-sudo`
- `--ap-start-script /opt/smartblaster/software/deploy/ap/start_ap_mode.sh`
- `--ap-stop-script /opt/smartblaster/software/deploy/ap/stop_ap_mode.sh`

## Sudo hardening for AP scripts

Install restricted sudoers file:
- Source: [software/deploy/security/smartblaster-apmode.sudoers](../../software/deploy/security/smartblaster-apmode.sudoers)
- Destination: `/etc/sudoers.d/smartblaster-apmode`
- Permissions: `0440`

Validate syntax before enabling:
- `sudo visudo -cf /etc/sudoers.d/smartblaster-apmode`

## AP mode scripts
- Start AP: [software/deploy/ap/start_ap_mode.sh](../../software/deploy/ap/start_ap_mode.sh)
- Stop AP: [software/deploy/ap/stop_ap_mode.sh](../../software/deploy/ap/stop_ap_mode.sh)
- Configs:
  - [software/deploy/ap/hostapd.conf](../../software/deploy/ap/hostapd.conf)
  - [software/deploy/ap/dnsmasq.conf](../../software/deploy/ap/dnsmasq.conf)

## Install steps (Raspberry Pi)
1. Copy project to `/opt/smartblaster/software`
2. Create and activate virtualenv; install dependencies
3. Copy service unit to `/etc/systemd/system/smartblaster.service`
4. Enable service:
   - `sudo systemctl daemon-reload`
   - `sudo systemctl enable smartblaster`
   - `sudo systemctl start smartblaster`

### Automated install (recommended)

Use the installer script:
- [software/deploy/install/install_service.sh](../../software/deploy/install/install_service.sh)
- Preflight checks: [software/deploy/install/preflight_check.sh](../../software/deploy/install/preflight_check.sh)
- Post-install checks: [software/deploy/install/post_install_check.sh](../../software/deploy/install/post_install_check.sh)

From `/opt/smartblaster/software`:
- `./deploy/install/preflight_check.sh`
- `sudo ./deploy/install/install_service.sh`
- `./deploy/install/post_install_check.sh`

Uninstall helper:
- [software/deploy/install/uninstall_service.sh](../../software/deploy/install/uninstall_service.sh)

## Notes
- AP scripts require root privileges.
- Tune interface names and conf paths per image.
- Recommended: a dedicated sudoers rule allowing only AP start/stop scripts.

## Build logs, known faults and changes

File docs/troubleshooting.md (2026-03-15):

# Troubleshooting

## Camera not detected
- Run `rpicam-hello` to verify camera is recognised by the OS
- Check CSI ribbon cable is fully seated and the locking tab is closed
- Ensure `camera_auto_detect=1` is set in `/boot/firmware/config.txt`

## IR not responding
- Verify wiring against [wiring.md](wiring.md)
- Test IR LED with a phone camera (should glow purple when active)
- Check GPIO pin assignments match `src/main.py` configuration

## Software won't start
- Confirm virtual environment is activated and `requirements.txt` is installed
- Check Python version: requires Python 3.9+
- Run `python src/main.py` directly to see stack traces

## Pi won't boot
- Re-flash SD card with latest Raspberry Pi OS (64-bit Lite recommended)
- Ensure power supply provides ≥3A

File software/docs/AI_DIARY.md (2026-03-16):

# AI Build Diary

## 2026-03-16 - Day 1 Product Assembly Milestone

This morning started with a practical homeowner problem: how to integrate HVAC behavior more intelligently with a new home solar system, without being boxed in by the limitations of commercial products. That led to a brainstorming session in ChatGPT around existing options such as Sensibo, where they fall short, and what a more flexible system might look like if it were designed from first principles.

Very quickly, that stopped being a vague idea and became a product concept. The ChatGPT phase helped collapse uncertainty fast: bill-of-materials planning, hardware tradeoffs, enclosure dimensions, measurement capture, and the rough path from concept to a printer-ready case model all came together quickly enough that turnkey hardware could be ordered for next-day delivery with real confidence.

That is an important part of the story because SmartBlaster was never just an app. Even on Day 1, the work already spanned hardware design and repo structure for electronics, enclosure work, and mechanical specifications, alongside assembly and wiring documentation. The physical side had enough definition to move from speculation to procurement.

Once the hardware was in motion, the work shifted into VS Code so the shipping time could be turned into implementation time. That handoff was the second half of the day: ChatGPT helped shape the physical product and validate that it was viable; GitHub Copilot in VS Code then helped turn the waiting window into a serious software sprint.

By the end of that sprint, SmartBlaster had gone from a blank slate to a working hybrid hardware/software product. The software side produced:
- A captive-portal provisioning flow that works from a phone browser
- Runtime failover back into setup mode when network connectivity is lost
- Unattended recovery from temporary network outages
- Primitive GitHub-based app updates
- Versioned setup-state persistence with migration hooks
- Owner-facing documentation for setup and operation
- An automated test suite covering provisioning, bootstrap, migration, and update paths

What makes the result satisfying is the breadth. In one day, the work covered software runtime, provisioning UX, update and recovery logic, documentation, tests, and the hardware groundwork needed to turn arriving parts into a real device rather than a slide-deck prototype.

Some Day 1 numbers are worth preserving:
- The working tree at this point spans 42 Python source files, 25 test files, and 2 markdown docs under `src`, `tests`, and `docs`.
- Those source, test, and doc files add up to 6,332 total lines.
- The setup portal now exposes 13 HTTP endpoints, covering setup, camera tools, device metadata, updates, reboot, and docs.
- The automated test suite already contains 99 explicit pytest test functions.
- The software stack pulls together 7 runtime libraries, plus 2 dev/test dependencies and 2 build-time packaging tools.
- Outside the software tree, the full SmartBlaster repo already carries dedicated hardware areas for electronics, enclosure design, and mechanical specifications, plus assembly and wiring documentation.

The practical outcome is already meaningful. This is good enough to pack in a suitcase, carry to a house, provision with only a phone, and use to gather real-world command-validation and reference-image data.

Tomorrow's practical milestone is even better: thanks to overnight delivery, nearly all reference hardware should be in hand and ready for first deployment testing.

Action items captured during this Day 1 checkpoint now live in `docs/PROJECT_BACKLOG.md` so planning can continue as a running project backlog instead of day-by-day TODO fragments.

The point of this diary is not hype. It is to keep a factual record of how AI-assisted engineering moved from a homeowner problem, to a validated design concept, to hardware on order, to a fairly complete first software implementation in roughly a day.

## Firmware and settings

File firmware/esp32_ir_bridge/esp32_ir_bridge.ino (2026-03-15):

// SmartBlaster ESP32 IR Bridge (reference scaffold)
// Receives line-delimited JSON over Serial and sends Midea AC IR.

#include <Arduino.h>
#include <ArduinoJson.h>
#include <IRremoteESP8266.h>
#include <IRsend.h>
#include <ir_Midea.h>

namespace {
constexpr uint16_t kIrLedPin = 4;  // change for your board wiring
constexpr uint32_t kBaudRate = 115200;

IRsend irsend(kIrLedPin);
IRMideaAC midea(kIrLedPin);

String readLine() {
  static String buf;
  while (Serial.available() > 0) {
    char c = static_cast<char>(Serial.read());
    if (c == '\n') {
      String line = buf;
      buf = "";
      return line;
    }
    if (c != '\r') buf += c;
  }
  return "";
}

void sendAck(const String &requestId, bool ok, const char *errorCode = nullptr, const char *errorMessage = nullptr) {
  StaticJsonDocument<256> ack;
  ack["v"] = 1;
  ack["topic"] = "midea_ir.ack";
  ack["request_id"] = requestId;
  ack["ok"] = ok;
  if (!ok) {
    ack["error_code"] = errorCode ? errorCode : "tx_failed";
    if (errorMessage) ack["error_message"] = errorMessage;
  }
  serializeJson(ack, Serial);
  Serial.println();
}

bool applyPayload(const JsonObject &payload, const String &requestId) {
  const char *mode = payload["mode"] | "off";

  if (strcmp(mode, "off") == 0) {
    midea.off();
    midea.send();
    return true;
  }

  if (!payload.containsKey("temperature_c")) {
    sendAck(requestId, false, "invalid_command", "temperature_c is required");
    return false;
  }

  float t = payload["temperature_c"].as<float>();
  if (t < 17 || t > 30) {
    sendAck(requestId, false, "invalid_command", "temperature_c out of range");
    return false;
  }

  midea.on();
  midea.setTemp(static_cast<uint8_t>(t));

  // Mode mapping (extend with model-specific validation as needed)
  if (strcmp(mode, "cool") == 0) midea.setMode(kMideaACCool);
  else if (strcmp(mode, "heat") == 0) midea.setMode(kMideaACHeat);
  else if (strcmp(mode, "dry") == 0) midea.setMode(kMideaACDry);
  else if (strcmp(mode, "fan_only") == 0) midea.setMode(kMideaACFan);
  else midea.setMode(kMideaACAuto);

  const char *fan = payload["fan"] | "auto";
  if (strcmp(fan, "low") == 0) midea.setFan(kMideaACFanLow);
  else if (strcmp(fan, "medium") == 0) midea.setFan(kMideaACFanMed);
  else if (strcmp(fan, "high") == 0) midea.setFan(kMideaACFanHigh);
  else midea.setFan(kMideaACFanAuto);

  // Swing toggle command can be model/state dependent.
  // Keep explicit toggle handling conservative in first revision.
  // TODO: map "swing" payload and special packet commands.

  midea.send();
  return true;
}

void handleLine(const String &line) {
  StaticJsonDocument<512> doc;
  auto err = deserializeJson(doc, line);
  if (err) {
    sendAck("", false, "bad_json", "invalid json");
    return;
  }

  JsonObject obj = doc.as<JsonObject>();
  int v = obj["v"] | -1;
  const char *topic = obj["topic"] | "";
  String requestId = String(obj["request_id"] | "");

  if (v != 1) {
    sendAck(requestId, false, "unsupported_version", "expected v=1");
    return;
  }
  if (strcmp(topic, "midea_ir.command") != 0) {
    sendAck(requestId, false, "bad_schema", "unsupported topic");
    return;
  }
  if (requestId.length() == 0) {
    sendAck(requestId, false, "bad_schema", "request_id required");
    return;
  }

  if (!obj.containsKey("payload") || !obj["payload"].is<JsonObject>()) {
    sendAck(requestId, false, "bad_schema", "payload object required");
    return;
  }

  JsonObject payload = obj["payload"].as<JsonObject>();
  bool ok = applyPayload(payload, requestId);
  if (ok) sendAck(requestId, true);
}
}  // namespace

void setup() {
  Serial.begin(kBaudRate);
  irsend.begin();
  midea.begin();
}

void loop() {
  String line = readLine();
  if (line.length() > 0) {
    handleLine(line);
  }
}

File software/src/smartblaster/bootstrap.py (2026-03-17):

"""Device bootstrap: choose setup portal vs runtime mode."""

from __future__ import annotations

import argparse
import json
import math
import os
from pathlib import Path
import re
import threading
import time

import uvicorn

from smartblaster.provisioning.ap_mode import ApModeController
from smartblaster.provisioning.service import ProvisioningService
from smartblaster.provisioning.state import load_setup_state
from smartblaster.provisioning.system import network_connected_best_effort, request_reboot, reboot_commands_from_env
from smartblaster.provisioning.web import create_provisioning_app
from smartblaster.services.runtime import SmartBlasterRuntime


def _setup_state_exists(state_file: Path) -> bool:
    return state_file.exists()


def _resolve_mode(
    requested_mode: str,
    *,
    state_exists: bool,
    network_connected: bool = True,
) -> str:
    """Decide operating mode.

    Boot-time logic ("auto"):
    - No saved state → setup (first-run provisioning, no auto-recover).
    - Saved state + WiFi not connected at boot → setup with auto-recover
      (allows user to re-enter credentials; reverts to runtime when WiFi returns).
    - Saved state + WiFi connected (or unknown) → runtime.
    """
    requested = requested_mode.lower().strip()
    if requested not in {"auto", "setup", "run"}:
        raise ValueError("mode must be one of: auto, setup, run")

    if requested == "auto":
        if not state_exists:
            return "setup"
        if not network_connected:
            return "setup"
        return "run"
    return requested


def _load_setup_state(state_file: Path) -> dict[str, object]:
    return load_setup_state(state_file)


def _apply_setup_state_to_env(setup: dict[str, object]) -> None:
    device_name = setup.get("device_name")
    if isinstance(device_name, str) and device_name.strip():
        os.environ.setdefault("SMARTBLASTER_DEVICE_NAME", device_name.strip())

    profile_id = setup.get("thermostat_profile_id")
    if isinstance(profile_id, str) and profile_id:
        os.environ.setdefault("SMARTBLASTER_THERMOSTAT_PROFILE_ID", profile_id)

    camera_enabled = setup.get("camera_enabled")
    if isinstance(camera_enabled, bool):
        os.environ.setdefault("SMARTBLASTER_CAMERA_ENABLED", "true" if camera_enabled else "false")

    # The simple schedule UI still stores legacy daily_* fields for preload purposes,
    # but runtime scheduling should prefer the explicit per-weekday schedule below.
    daily_on_time = setup.get("daily_on_time")
    if isinstance(daily_on_time, str) and _is_valid_hhmm(daily_on_time):
        os.environ.setdefault("SMARTBLASTER_DAILY_ON_TIME", daily_on_time)

    daily_off_time = setup.get("daily_off_time")
    if isinstance(daily_off_time, str) and _is_valid_hhmm(daily_off_time):
        os.environ.setdefault("SMARTBLASTER_DAILY_OFF_TIME", daily_off_time)

    # Canonical schedule source of truth: one entry per weekday. The portal's simple
    # mode writes the same value into every day so runtime does not need a second path.
    weekly_schedule = setup.get("solar_weekly_schedule")
    if isinstance(weekly_schedule, dict) and weekly_schedule:
        os.environ.setdefault("SMARTBLASTER_SOLAR_WEEKLY_SCHEDULE_JSON", json.dumps(weekly_schedule))

    target_temperature_c = setup.get("target_temperature_c")
    if isinstance(target_temperature_c, (int, float)) and math.isfinite(float(target_temperature_c)):
        os.environ.setdefault("SMARTBLASTER_TARGET_TEMPERATURE_C", str(float(target_temperature_c)))

    timezone = setup.get("timezone")
    if isinstance(timezone, str) and timezone.strip():
        os.environ.setdefault("SMARTBLASTER_TIMEZONE", timezone)

    active_days = setup.get("active_days")
    if isinstance(active_days, list):
        normalized_days = [str(item).strip().lower() for item in active_days if str(item).strip()]
        if normalized_days:
            os.environ.setdefault("SMARTBLASTER_ACTIVE_DAYS", ",".join(normalized_days))

    fan_mode = setup.get("fan_mode")
    if isinstance(fan_mode, str) and fan_mode:
        os.environ.setdefault("SMARTBLASTER_FAN_MODE", fan_mode)

    swing_mode = setup.get("swing_mode")
    if isinstance(swing_mode, str) and swing_mode:
        os.environ.setdefault("SMARTBLASTER_SWING_MODE", swing_mode)

    preset_mode = setup.get("preset_mode")
    if isinstance(preset_mode, str) and preset_mode:
        os.environ.setdefault("SMARTBLASTER_PRESET_MODE", preset_mode)

    thermostat_temperature_unit = setup.get("thermostat_temperature_unit")
    if isinstance(thermostat_temperature_unit, str) and thermostat_temperature_unit.strip().upper() in {"C", "F"}:
        os.environ.setdefault("SMARTBLASTER_THERMOSTAT_TEMPERATURE_UNIT", thermostat_temperature_unit.strip().upper())

    inverter_source_enabled = setup.get("inverter_source_enabled")
    if isinstance(inverter_source_enabled, bool):
        os.environ.setdefault(
            "SMARTBLASTER_INVERTER_SOURCE_ENABLED",
            "true" if inverter_source_enabled else "false",
        )

    inverter_source_type = setup.get("inverter_source_type")
    if isinstance(inverter_source_type, str) and inverter_source_type.strip():
        os.environ.setdefault("SMARTBLASTER_INVERTER_SOURCE_TYPE", inverter_source_type)

    inverter_surplus_start_w = setup.get("inverter_surplus_start_w")
    if isinstance(inverter_surplus_start_w, int):
        os.environ.setdefault("SMARTBLASTER_INVERTER_SURPLUS_START_W", str(inverter_surplus_start_w))

    inverter_surplus_stop_w = setup.get("inverter_surplus_stop_w")
    if isinstance(inverter_surplus_stop_w, int):
        os.environ.setdefault("SMARTBLASTER_INVERTER_SURPLUS_STOP_W", str(inverter_surplus_stop_w))

    status_history_file = setup.get("status_history_file")
    if isinstance(status_history_file, str) and status_history_file.strip():
        os.environ.setdefault("SMARTBLASTER_STATUS_HISTORY_FILE", status_history_file)

    status_diagnostic_mode = setup.get("status_diagnostic_mode")
    if isinstance(status_diagnostic_mode, bool):
        os.environ.setdefault(
            "SMARTBLASTER_STATUS_DIAGNOSTIC_MODE",
            "true" if status_diagnostic_mode else "false",
        )

    status_image_dir = setup.get("status_image_dir")
    if isinstance(status_image_dir, str) and status_image_dir.strip():
        os.environ.setdefault("SMARTBLASTER_STATUS_IMAGE_DIR", status_image_dir)

    reference_image_dir = setup.get("reference_image_dir")
    if isinstance(reference_image_dir, str) and reference_image_dir.strip():
        os.environ.setdefault("SMARTBLASTER_REFERENCE_IMAGE_DIR", reference_image_dir)

    reference_capture_on_parse_failure = setup.get("reference_capture_on_parse_failure")
    if isinstance(reference_capture_on_parse_failure, bool):
        os.environ.setdefault(
            "SMARTBLASTER_REFERENCE_CAPTURE_ON_PARSE_FAILURE",
            "true" if reference_capture_on_parse_failure else "false",
        )
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

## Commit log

2026-03-15 Initial commit: SmartBlaster repo scaffold
    [bill_of_materials.csv, camera_bracket.obj, ir_mount.obj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]
2026-03-16 Checkpoint: vision parsing pipeline and robust ROI groundwork
2026-03-16 Checkpoint: stabilize LCD alignment and icon occupancy parsing
    [cli.py]
2026-03-16 Checkpoint: temperature decoder instrumentation and candidate search
2026-03-16 Temperature: add anchored ROI gating and right-shift candidates
2026-03-16 Provisioning: add camera setup preview and reference capture
2026-03-16 Runtime: capture failed thermostat frames for diagnostics
    [bootstrap.py, config.py]
2026-03-16 Runtime: alert when expected camera becomes unavailable
2026-03-16 Runtime: remove proactive camera health polling
2026-03-16 feat: setup validation workflow (backlog item 2)
    - services/setup_validation.py: SetupValidator runs cool/heat/dry/fan_only/off
    sequence, compares camera-parsed DisplayMode and power_on against expected,
    returns ValidationReport with per-step outcomes and confidence scores
    - provisioning/web.py: POST /api/validation/run endpoint + ValidationRunPayload;
    validation panel in portal HTML (shown only when camera is enabled) with
    settle-time input, Run button, and per-step results table
    - tests/test_setup_validation.py: 15 tests covering skip (no camera), all-pass,
    wrong-mode fail, parse-fail, camera-error, OFF special logic, JSON round-trip,
    and sleep-fn injection; 133 passed
2026-03-16 checkpoint: solar schedule + setup validation milestone
    - add weekly solar surplus/deficit scheduling support with per-day structure
    - keep backward compatibility with legacy daily on/off + active days
    - set default schedule to 10:00 on / 15:00 off
    - set default cooling target to 26C (~78F)
    - expand setup validation to exercise broad IR command variants
    - add required cool_26 -> cool_24 setpoint verification
    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
2026-03-16 checkpoint: ready-to-boot Pi image assets
    - add first-boot setup script for SmartBlaster on Pi OS Lite
    - add package install script for OpenCV, Tesseract, and TFLite runtime (best-effort)
    - add Pi image preparation checklist for new users
    - document deployment flow and script locations in README
    - keep local vision evaluation report untracked
2026-03-16 Add tests for camera CTA, Copy Diagnostics, and has_camera_setup_values in device-info
2026-03-16 Replace force_setup_on_next_boot with boot-time WiFi check; runtime runs regardless of network state
    - _resolve_mode now takes network_connected (bool) instead of setup_state dict;
    returns 'setup' when state exists but WiFi is absent at boot
    - _wait_for_network_at_boot polls up to SMARTBLASTER_NETWORK_BOOT_WAIT_SECONDS
    (default 60 s) so a Pi that reboots faster than the router after a power
    outage doesn't incorrectly land in the captive portal
    - runtime.run_forever() no longer guards on network; scheduler always runs
    - Removed RuntimeNetworkUnavailable and force_setup_on_next_boot entirely
    - Tests updated accordingly (147 passing)
    [bootstrap.py]
2026-03-17 revA enclosure: snap-fit/lip-groove refactor checkpoint
    [smartblaster_reva.scad]
2026-03-17 revA enclosure: add mating debug preview and back-shell attachment fixes
    [smartblaster_reva.scad]
2026-03-17 fix(revA scad): resolve render undef vars and attach mating tabs
    [smartblaster_reva.scad]
2026-03-17 fix(revA scad): correct front shell orientation and rear opening
    [smartblaster_reva.scad]
2026-03-17 feat(revA scad): replace protruding boss with flush Blink snap-in socket
    [smartblaster_reva.scad]
2026-03-17 feat(enclosure/lib): add shared blink_mount_socket.scad library with full provenance
    [smartblaster_reva.scad]
2026-03-17 fix(enclosure): replace oversize inward socket with correct shallow outward snap collar
    Blink fixed-mount bracket peg is tiny: bore ~8.5 mm, collar OD 14 mm,
    protrusion ~2 mm (PCB-thickness). Previous implementation was ~40 mm
    diameter and protruded inward -- both wrong.
    Changes:
    - Params: blink_socket_d/snap_d/snap_depth/stem_d -> blink_collar_od (14),
    blink_bore_d (8.5), blink_collar_h (2.0), blink_vent_clear_r (10.0)
    - back_shell union: shallow annular ring protruding outward from exterior face
    - back_shell difference: single 8.5 mm bore through wall + collar;
    vent loop now skips hexes within 10 mm of centre
    - back_attached_features_preview: updated to new params
    - lib/blink_mount_s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
    [smartblaster_reva.scad]
2026-03-17 feat(enclosure): component layout, camera mounts, LED shelf, vent zoning
    Layout changes:
    - Camera shifted to -X side (cam_offset_x=-18); Pi rotated 90 deg and
    offset to +X side (pi_offset_x=30) to separate the two components
    - Screw posts pushed to 10mm corner inset to clear Pi standoffs
    - Blink wall-mount collar recentred on camera lens (cam_offset_x, cam_offset_y)
    so wall attachment resists lens torque directly
    Camera mounting:
    - 4-boss square pattern (27mm C-C from mechanical drawing) rising 10mm
    from back shell floor; pilot holes sized for M2.5
    - Camera mount bosses moved from front shell to back shell (correct side)
    LED board mount (front shell):
    - Drawer-glide shelf with side r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
    [smartblaster_reva.scad]
2026-03-17 chore(hardware): add camera reference images for mechanical spec work
2026-03-17 feat(enclosure): checkpoint ready-to-print RevA case layout
    Checkpoint includes:
    - Camera mount in upper-left (SCAD axes) with 5mm inboard border to walls
    - Pi standoffs in lower-right, landscape orientation, with pilot holes
    - Legacy corner screw posts removed (snap-fit closure only)
    - Camera retention frame refined (32.4mm inner capture, floor flush to post tops)
    - Blink wall mount shifted inward so back exterior remains flush
    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
    [smartblaster_reva.scad]
2026-03-17 chore(hardware): add Pi3 reference images for connector/mechanical layout
2026-03-18 CameraService: add USB (OpenCV) support, fallback to Pi camera
2026-04-02 fix: use smartblaster-device entrypoint in service (portal working)
2026-04-02 fix: add opencv-python-headless dependency for USB camera support
2026-04-02 improve Pi update flow: one-command deploy + checklist guidance
2026-04-02 fix(camera setup): serialize preview/status camera access
2026-04-02 Fix service WorkingDirectory; debug camera image saves
2026-04-02 Fix camera_setup.py: restore _analyze_frame as class method
2026-04-02 Fix portal preview: use full-frame overlay, keep camera warm between requests
2026-04-02 Fix camera: prefer picamera2 over OpenCV to avoid black frames on Pi
    [camera.py]
2026-04-02 Fix camera: restore USB-first, bypass PIL processing for raw preview
    [camera.py]
2026-04-02 Portal: keep USB camera alive between requests to avoid black warmup frames
2026-04-02 Fix modal live view: stop clearing image on error, pause panel timer while modal open
2026-04-02 Fix live view: chain frame requests off onload to prevent race condition
2026-04-02 Restore working March 19 live view JS: simple setInterval, no onload chaining
2026-04-02 Revert to manage_camera_lifecycle=True: retry camera start on each request
2026-04-02 Fix camera: lazy start + keep alive in portal; stop rapid open/close cycle
2026-04-02 Fix stale frames: flush OpenCV buffer before capture; slow live view to 2s
    [camera.py]
2026-04-02 Enable overlay on camera live view
